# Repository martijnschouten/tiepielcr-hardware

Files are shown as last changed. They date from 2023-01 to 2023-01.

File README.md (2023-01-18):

# TiePieLCR hardware
Contains the design files of the TiePieLCR multi-frequency spectrometer front-end. The TiePieLCR consists of a TiePie engineering HS5 with custom PCB and a 3D printed case. The front-end contains an instrumentation amplifier to measure differential voltages, a transimpedance amplifier to measure currents and  voltage controlled current source to be able to do safe current controlled measurements on humans.

To make one of your own you can use the supplied gerber files to get a PCB fabricated. To make some improments to design you can open the schematic in Kicad. The STL's and Inventor files of the case for the electronics can also be found in this repository.



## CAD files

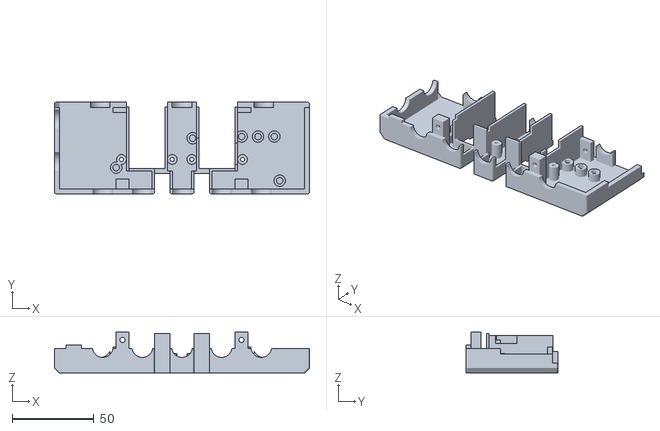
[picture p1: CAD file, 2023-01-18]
casing/Part1.stl
156.0 x 56.0 x 25.0

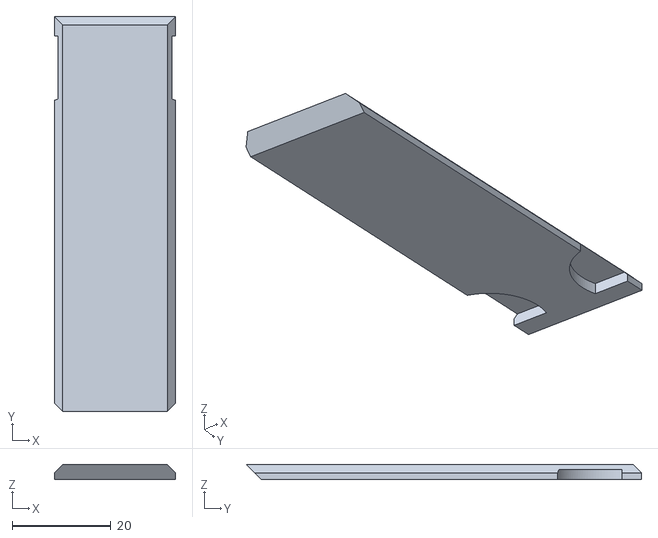
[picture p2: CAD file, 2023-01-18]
casing/Part3.stl
24.6 x 80.1 x 3.00

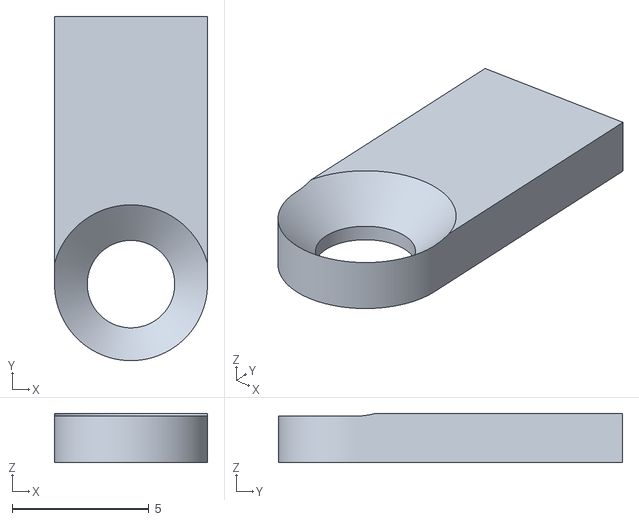
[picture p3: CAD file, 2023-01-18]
casing/Part4.stl
5.60 x 12.6 x 1.80

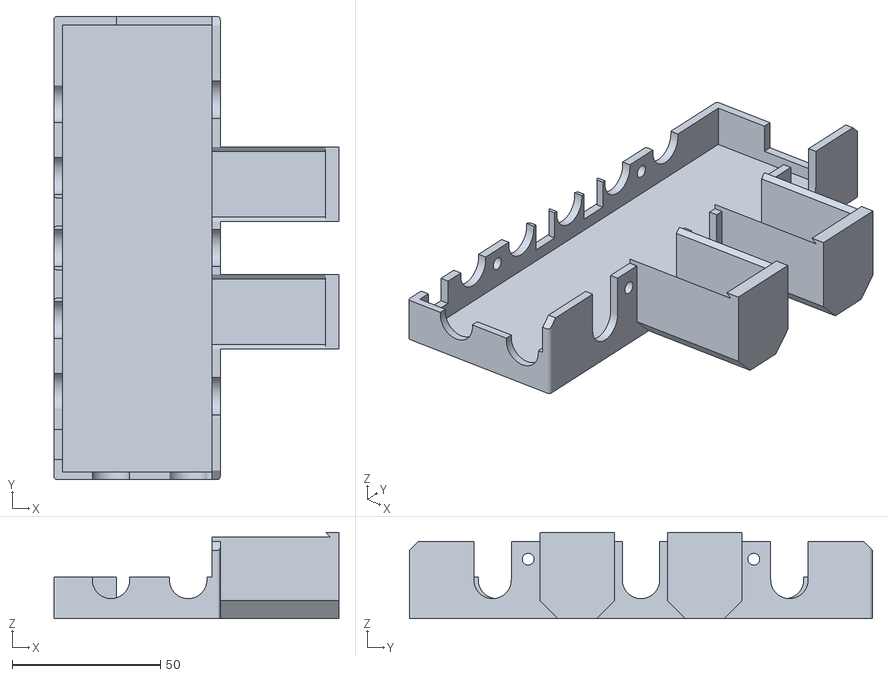
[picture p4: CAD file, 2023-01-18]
casing/Part2.stl
96.0 x 156.0 x 29.0

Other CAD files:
casing/Assembly1.iam
casing/Part1.ipt
casing/Part2.ipt
casing/Part3.ipt
casing/Part4.ipt

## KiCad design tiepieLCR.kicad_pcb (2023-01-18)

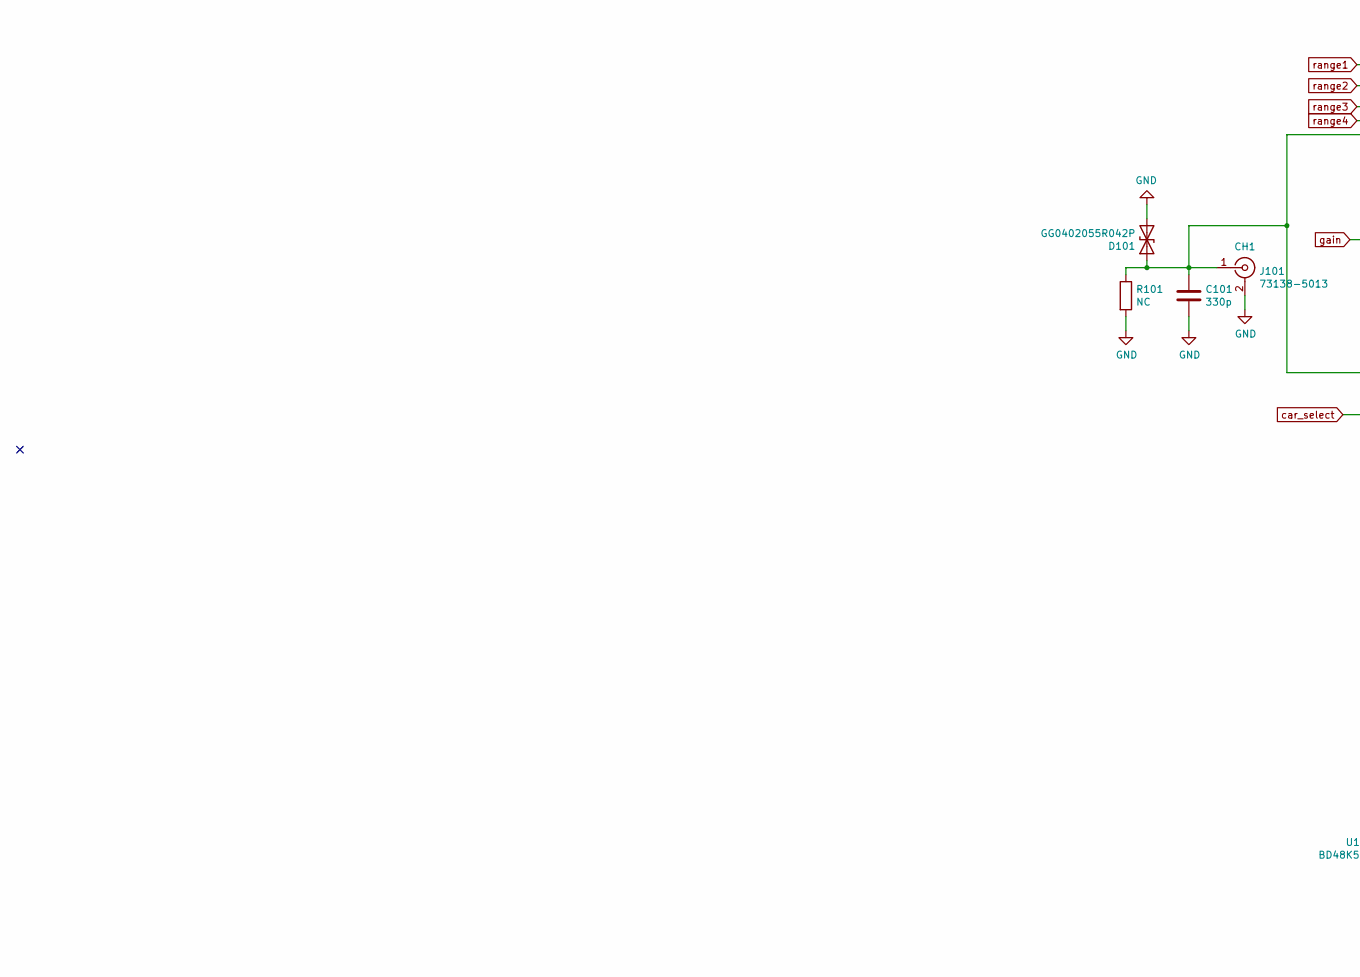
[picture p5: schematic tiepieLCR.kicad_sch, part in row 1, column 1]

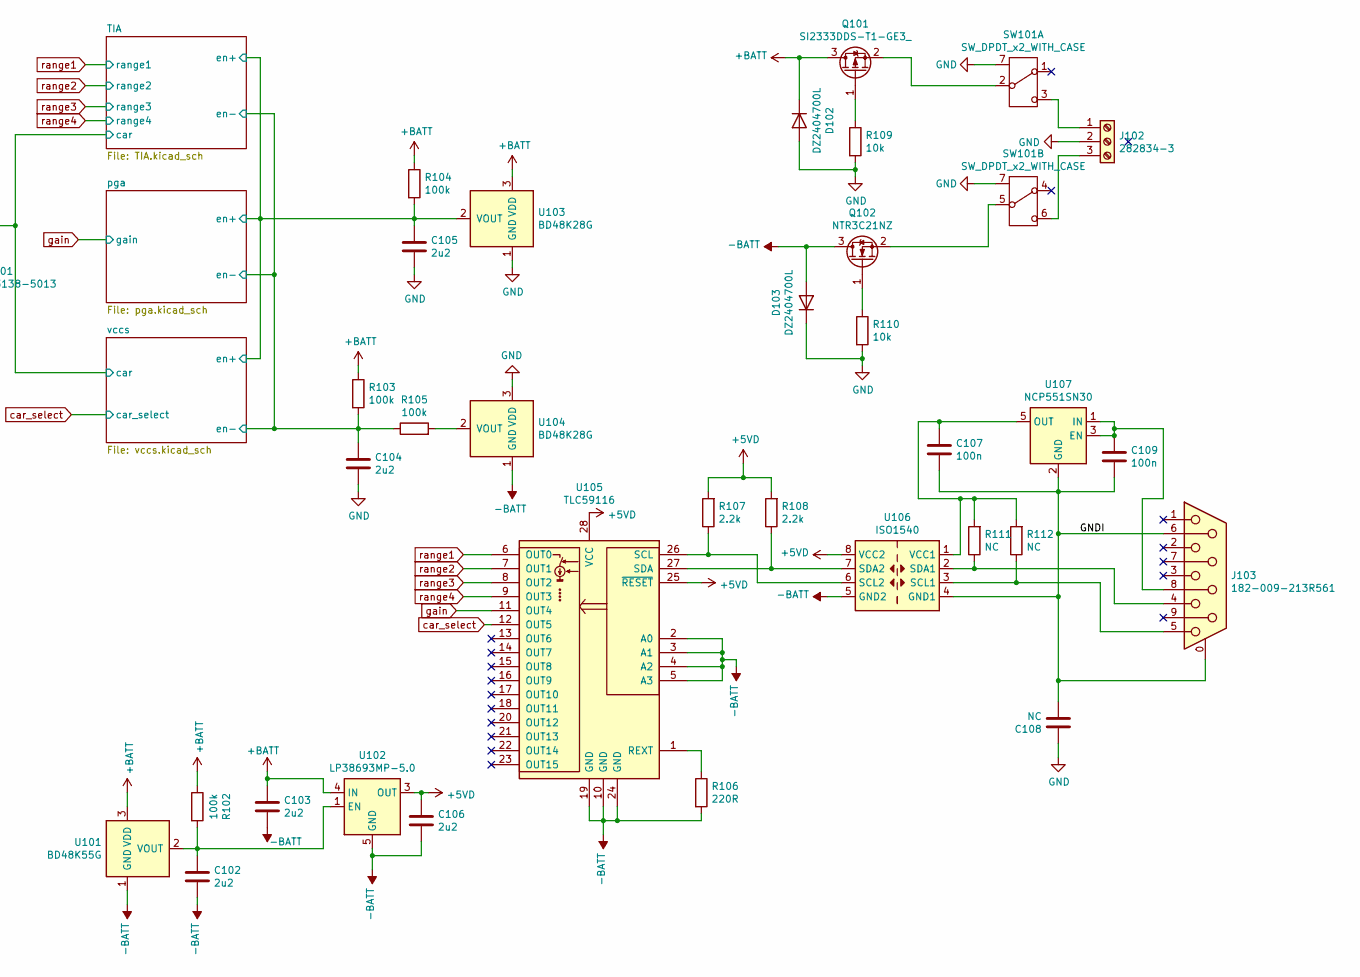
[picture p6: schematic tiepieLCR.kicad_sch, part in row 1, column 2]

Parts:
C101: 330p; C_0603_1608Metric_Pad1.05x0.95mm_HandSolder
C102, C103, C104, C105, C106: 2u2; C_0603_1608Metric_Pad1.05x0.95mm_HandSolder
C107, C109: 100n; C_0603_1608Metric_Pad1.05x0.95mm_HandSolder
C108: NC; C_1206_3216Metric
D101: GG0402055R042P; D_0402_1005Metric
D102, D103: DZ2404700L; D_SOD-128
J101: 73138-5013; 0731385033
J102: 282834-3; TerminalBlock_TE_282834-3_1x03_P2.54mm_Horizontal
J103: 182-009-213R561; DSUB-9_Female_Horizontal_P2.77x2.84mm_EdgePinOffset7.70mm_H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
Q101: SI2333DDS-T1-GE3_; SOT-23
Q102: NTR3C21NZ; SOT-23
R101, R111, R112: NC; R_0603_1608Metric_Pad1.05x0.95mm_HandSolder
R102, R103, R104, R105: 100k; R_0603_1608Metric_Pad1.05x0.95mm_HandSolder
R106: 220R; R_0603_1608Metric_Pad1.05x0.95mm_HandSolder
R107, R108: 2.2k; R_0603_1608Metric_Pad1.05x0.95mm_HandSolder
R109, R110: 10k; R_0603_1608Metric_Pad1.05x0.95mm_HandSolder
SW101: SW_DPDT_x2_WITH_CASE; EG2219
U101: BD48K55G; SOT-23
U102: LP38693MP-5.0; SOT-223-5
U103, U104: BD48K28G; SOT-23
U105: TLC59116; TSSOP-28_4.4x9.7mm_P0.65mm
U106: ISO1540; SOIC-8_3.9x4.9mm_P1.27mm
U107: NCP551SN30; SOT-23-5

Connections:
+5VD: C106.1, R107.2, R108.2, U102.3 (OUT), U105.25 (~RESET), U105.28 (VCC), U106.8 (VCC2); also elsewhere on the board
+BATT: C103.1, D102.1 (K), Q101.3 (D), R102.1, R103.1, R104.1, U101.3 (VDD), U102.4 (IN), U103.3 (VDD); also elsewhere on the board
-BATT: C102.2, C103.2, C106.2, D103.2 (A), Q102.3 (D), R106.2, U101.1 (GND), U102.5 (GND), U104.1 (GND), U105.2 (A0), U105.3 (A1), U105.4 (A2), U105.5 (A3), U105.10 (GND), U105.19 (GND), U105.24 (GND), U106.5 (GND2); also elsewhere on the board
/GNDI: C107.2, C108.2, C109.2, J103.0 (PAD), J103.6 (GND), U106.4 (GND1), U107.2 (GND)
/TIA/car: C101.1, D101.1 (A1), J101.1 (In), R101.1; also elsewhere on the board
/TIA/en+: C105.1, R104.2, U103.2 (VOUT); also elsewhere on the board
/TIA/en-: C104.1, R103.2, R105.1; also elsewhere on the board
GND: C101.2, C104.2, C105.2, C108.1, D101.2 (A2), D102.2 (A), D103.1 (K), J101.2 (Ext), J102.2, R101.2, R109.2, R110.2, SW101.7 (CASE), U103.1 (GND), U104.3 (VDD); also elsewhere on the board
unnamed: C102.1, R102.2, U101.2 (VOUT), U102.1 (EN)
unnamed: C107.1, R111.2, R112.2, U106.1 (VCC1), U107.5 (OUT)
unnamed: C109.1, J103.8 (OUT), U107.1 (IN), U107.3 (EN)
unnamed: J102.1, SW101.3 (C)
unnamed: J102.3, SW101.6 (C)
unnamed: J103.4 (SDA), R111.1, U106.2 (SDA1)
unnamed: J103.5 (SCL), R112.1, U106.3 (SCL1)
unnamed: Q101.1 (G), R109.1
unnamed: Q101.2 (S), SW101.2 (B)
unnamed: Q102.1 (G), R110.1
unnamed: Q102.2 (S), SW101.5 (B)
unnamed: R105.2, U104.2 (VOUT)
unnamed: R106.1, U105.1 (REXT)
unnamed: R107.1, U105.26 (SCL), U106.6 (SCL2)
unnamed: R108.1, U105.27 (SDA), U106.7 (SDA2)
car_select: U105.12 (OUT5); also elsewhere on the board
gain: U105.11 (OUT4); also elsewhere on the board
range1: U105.6 (OUT0); also elsewhere on the board
range2: U105.7 (OUT1); also elsewhere on the board
range3: U105.8 (OUT2); also elsewhere on the board
range4: U105.9 (OUT3); also elsewhere on the board

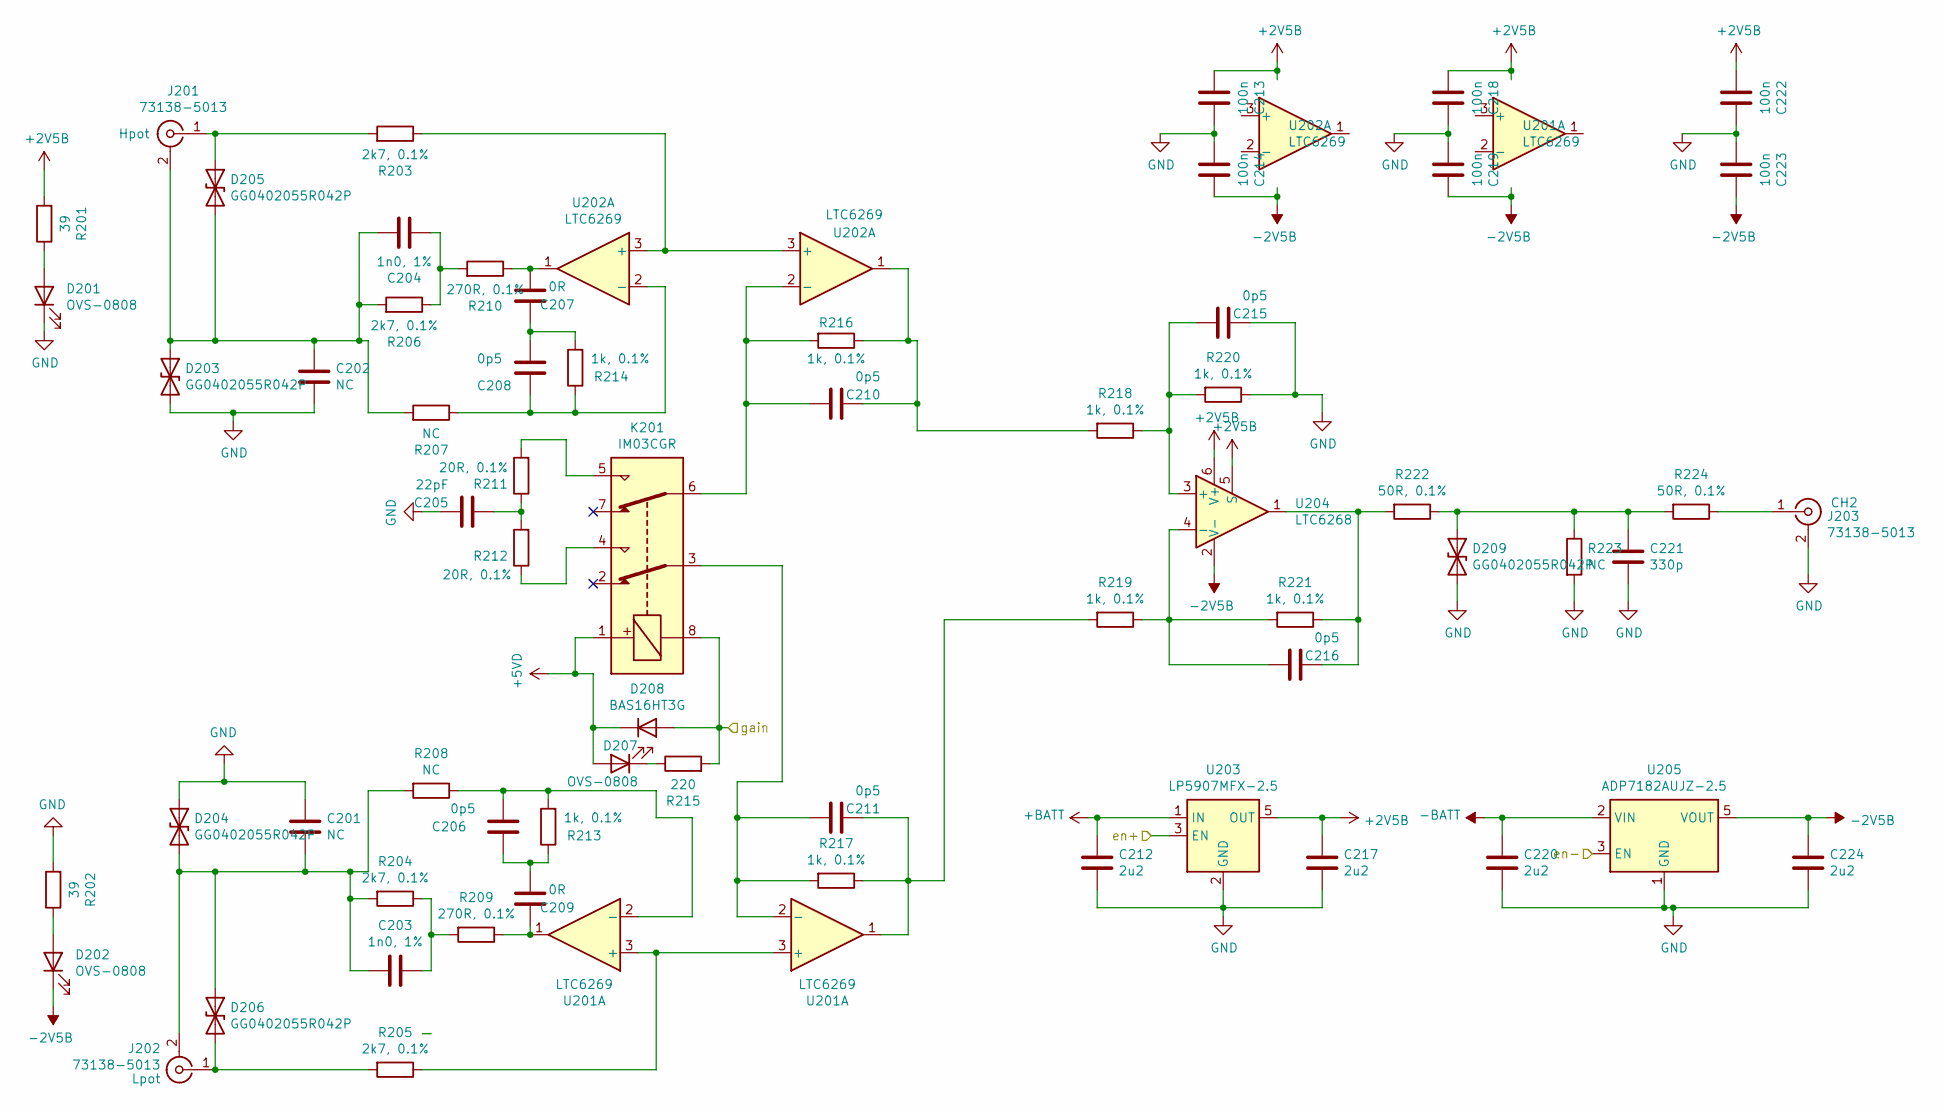
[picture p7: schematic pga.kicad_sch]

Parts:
C201, C202: NC; C_0603_1608Metric_Pad1.05x0.95mm_HandSolder
C203, C204: 1n0, 1%; C_0603_1608Metric_Pad1.05x0.95mm_HandSolder
C205: 22pF; C_0603_1608Metric_Pad1.05x0.95mm_HandSolder
C206, C208, C210, C211, C215, C216: 0p5; C_0603_1608Metric_Pad1.05x0.95mm_HandSolder
C207, C209: 0R; C_0603_1608Metric_Pad1.05x0.95mm_HandSolder
C212, C217, C220, C224: 2u2; C_0603_1608Metric_Pad1.05x0.95mm_HandSolder
C213, C214, C218, C219, C222, C223: 100n; C_0603_1608Metric_Pad1.05x0.95mm_HandSolder
C221: 330p; C_0603_1608Metric_Pad1.05x0.95mm_HandSolder
D201, D202, D207: OVS-0808; LED_0805_2012Metric
D203, D204, D205, D206, D209: GG0402055R042P; D_0402_1005Metric
D208: BAS16HT3G; D_SOD-323
J201, J202, J203: 73138-5013; 0731385033
K201: IM03CGR; 1462039-4
R201, R202: 39; R_0603_1608Metric_Pad1.05x0.95mm_HandSolder
R203, R204, R205, R206: 2k7, 0.1%; R_0603_1608Metric_Pad1.05x0.95mm_HandSolder
R207, R208, R223: NC; R_0603_1608Metric_Pad1.05x0.95mm_HandSolder
R209, R210: 270R, 0.1%; R_0603_1608Metric_Pad1.05x0.95mm_HandSolder
R211, R212: 20R, 0.1%; R_0603_1608Metric_Pad1.05x0.95mm_HandSolder
R213, R214, R216, R217, R218, R219, R220, R221: 1k, 0.1%; R_0603_1608Metric
R215: 220; R_0603_1608Metric_Pad1.05x0.95mm_HandSolder
R222, R224: 50R, 0.1%; R_0603_1608Metric
U201, U202: LTC6269; MSOP-8_3x3mm_P0.65mm
U203: LP5907MFX-2.5; SOT-23-5
U204: LTC6268; SOT-23-6_Handsoldering
U205: ADP7182AUJZ-2.5; TSOT-23-5

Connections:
+2V5B: C213.2, C217.2, C218.2, C222.2, R201.2, U201.8 (V+), U202.8 (V+), U203.5 (OUT), U204.5 (S), U204.6 (V+)
+5VD: D207.2 (A), D208.1 (K), K201.1; also elsewhere on the board
+BATT: C212.2, U203.1 (IN); also elsewhere on the board
-2V5B: C214.1, C219.1, C223.1, C224.2, D202.1 (K), U201.4 (V-), U202.4 (V-), U204.2 (V-), U205.5 (VOUT)
-BATT: C220.2, U205.2 (VIN); also elsewhere on the board
/TIA/en+: U203.3 (EN); also elsewhere on the board
/TIA/en-: U205.3 (EN); also elsewhere on the board
GND: C201.1, C202.2, C205.2, C212.1, C213.1, C214.2, C215.1, C217.1, C218.1, C219.2, C220.1, C221.2, C222.1, C223.2, C224.1, D201.1 (K), D203.2 (A2), D204.1 (A1), D209.2 (A2), J203.2 (Ext), R202.2, R220.1, R223.2, U203.2 (GND), U205.1 (GND); also elsewhere on the board
unnamed: C201.2, C203.2, D204.2 (A2), D206.1 (A1), J202.2 (Ext), R204.2, R208.2
unnamed: C202.1, C204.2, D203.1 (A1), D205.2 (A2), J201.2 (Ext), R206.2, R207.2
unnamed: C203.1, R204.1, R209.2
unnamed: C204.1, R206.1, R210.2
unnamed: C205.1, R211.1, R212.2
unnamed: C206.2, C209.2, R213.1
unnamed: C207.1, C208.1, R214.2
unnamed: C215.2, R218.1, R220.2, U204.3 (+)
unnamed: C216.1, R221.1, R222.2, U204.1
unnamed: C216.2, R219.1, R221.2, U204.4 (-)
unnamed: C221.1, D209.1 (A1), R222.1, R223.1, R224.2
unnamed: D201.2 (A), R201.1
unnamed: D202.2 (A), R202.1
unnamed: D205.1 (A1), J201.1 (In), R203.2
unnamed: D206.2 (A2), J202.1 (In), R205.2
unnamed: D207.1 (K), R215.1
unnamed: J203.1 (In), R224.1
unnamed: K201.4, R212.1
unnamed: K201.5, R211.2
unnamed: R203.1, U202.3 (+), U202.5 (+)
unnamed: R205.1, U201.3 (+), U201.5 (+)
gain: D208.2 (A), K201.8, R215.2; also elsewhere on the board

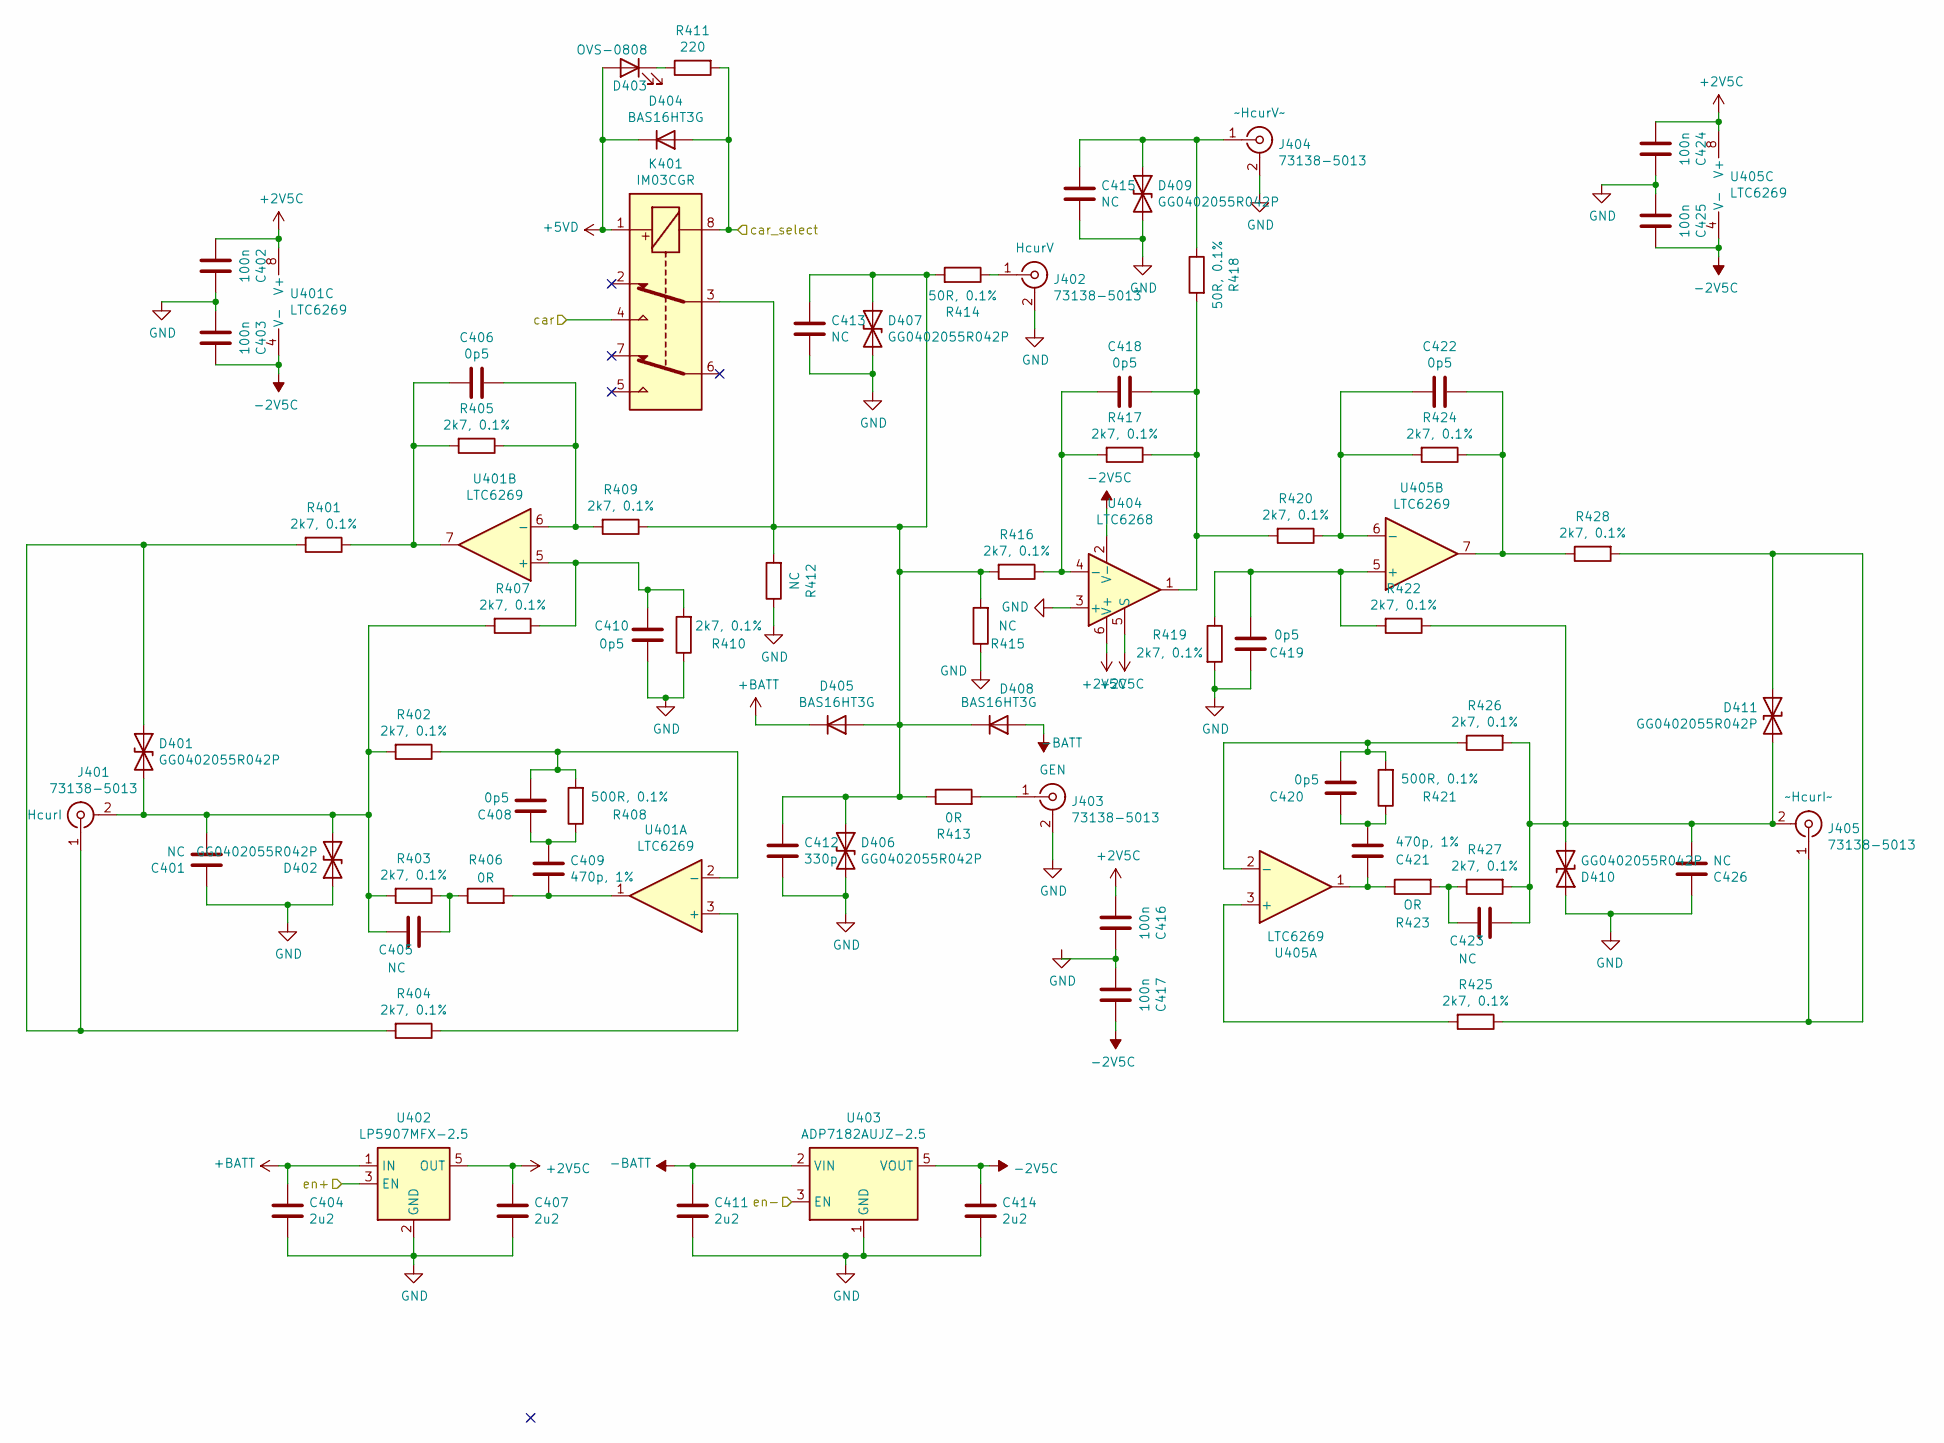
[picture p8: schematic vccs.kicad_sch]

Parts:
C401, C405, C413, C415, C423, C426: NC; C_0603_1608Metric_Pad1.05x0.95mm_HandSolder
C402, C403, C416, C417, C424, C425: 100n; C_0603_1608Metric_Pad1.05x0.95mm_HandSolder
C404, C407, C411, C414: 2u2; C_0603_1608Metric_Pad1.05x0.95mm_HandSolder
C406, C408, C410, C418, C419, C420, C422: 0p5; C_0603_1608Metric_Pad1.05x0.95mm_HandSolder
C409, C421: 470p, 1%; C_0603_1608Metric_Pad1.05x0.95mm_HandSolder
C412: 330p; C_0603_1608Metric_Pad1.05x0.95mm_HandSolder
D401, D402, D406, D407, D409, D410, D411: GG0402055R042P; D_0402_1005Metric
D403: OVS-0808; LED_0805_2012Metric
D404, D405, D408: BAS16HT3G; D_SOD-323
J401, J402, J403, J404, J405: 73138-5013; 0731385033
K401: IM03CGR; 1462039-4
R401, R402, R403, R404, R405, R407, R409, R410, R416, R417, R419, R420, R422, R424, R425, R426, R427, R428: 2k7, 0.1%; R_0603_1608Metric_Pad1.05x0.95mm_HandSolder
R406, R413: 0R; R_0603_1608Metric_Pad1.05x0.95mm_HandSolder
R408, R421: 500R, 0.1%; R_0603_1608Metric_Pad1.05x0.95mm_HandSolder
R411: 220; R_0603_1608Metric_Pad1.05x0.95mm_HandSolder
R412, R415: NC; R_0603_1608Metric_Pad1.05x0.95mm_HandSolder
R414, R418: 50R, 0.1%; R_0603_1608Metric
R423: OR; R_0603_1608Metric_Pad1.05x0.95mm_HandSolder
U401, U405: LTC6269; MSOP-8_3x3mm_P0.65mm
U402: LP5907MFX-2.5; SOT-23-5
U403: ADP7182AUJZ-2.5; TSOT-23-5
U404: LTC6268; SOT-23-6_Handsoldering

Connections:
+2V5C: C402.2, C407.2, C416.2, C424.2, U401.8 (V+), U402.5 (OUT), U404.5 (S), U404.6 (V+), U405.8 (V+)
+5VD: D403.2 (A), D404.1 (K), K401.1; also elsewhere on the board
+BATT: C404.2, D405.1 (K), U402.1 (IN); also elsewhere on the board
-2V5C: C403.1, C414.2, C417.1, C425.1, U401.4 (V-), U403.5 (VOUT), U404.2 (V-), U405.4 (V-)
-BATT: C411.2, D408.2 (A), U403.2 (VIN); also elsewhere on the board
/TIA/car: K401.4; also elsewhere on the board
/TIA/en+: U402.3 (EN); also elsewhere on the board
/TIA/en-: U403.3 (EN); also elsewhere on the board
GND: C401.1, C402.1, C403.2, C404.1, C407.1, C410.2, C411.1, C412.1, C413.1, C414.1, C415.1, C419.2, C424.1, C425.2, C426.1, D402.1 (A1), D406.2 (A2), D407.2 (A2), D409.2 (A2), D410.1 (A1), J402.2 (Ext), J403.2 (Ext), J404.2 (Ext), R410.1, R412.1, R415.1, R419.2, U402.2 (GND), U403.1 (GND), U404.3 (+); also elsewhere on the board
unnamed: C401.2, C405.1, D401.2 (A2), D402.2 (A2), J401.2 (Ext), R402.2, R403.2, R407.2
unnamed: C405.2, R403.1, R406.1
unnamed: C406.1, R405.1, R409.2, U401.6 (-)
unnamed: C406.2, R401.1, R405.2, U401.7
unnamed: C408.1, R402.1, R408.2, U401.2 (-)
unnamed: C408.2, C409.2, R408.1
unnamed: C409.1, R406.2, U401.1
unnamed: C410.1, R407.1, R410.2, U401.5 (+)
unnamed: C412.2, C413.2, D405.2 (A), D406.1 (A1), D407.1 (A1), D408.1 (K), K401.3, R409.1, R412.2, R413.1, R414.2, R415.2, R416.2
unnamed: C415.2, D409.1 (A1), J404.1 (In), R418.1
unnamed: C416.1, C417.2
unnamed: C418.1, R417.1, R418.2, R420.2, U404.1
unnamed: C418.2, R416.1, R417.2, U404.4 (-)
unnamed: C419.1, R419.1, R422.2, U405.5 (+)
unnamed: C420.1, R421.2, R426.1, U405.2 (-)
unnamed: C420.2, C421.2, R421.1
unnamed: C421.1, R423.1, U405.1
unnamed: C422.1, R420.1, R424.2, U405.6 (-)
unnamed: C422.2, R424.1, R428.1, U405.7
unnamed: C423.1, R423.2, R427.1
unnamed: C423.2, C426.2, D410.2 (A2), D411.2 (A2), J405.2 (Ext), R422.1, R426.2, R427.2
unnamed: D401.1 (A1), J401.1 (In), R401.2, R404.2
unnamed: D403.1 (K), R411.1
unnamed: D411.1 (A1), J405.1 (In), R425.1, R428.2
unnamed: J402.1 (In), R414.1
unnamed: J403.1 (In), R413.2
unnamed: R404.1, U401.3 (+)
unnamed: R425.2, U405.3 (+)
car_select: D404.2 (A), K401.8, R411.2; also elsewhere on the board

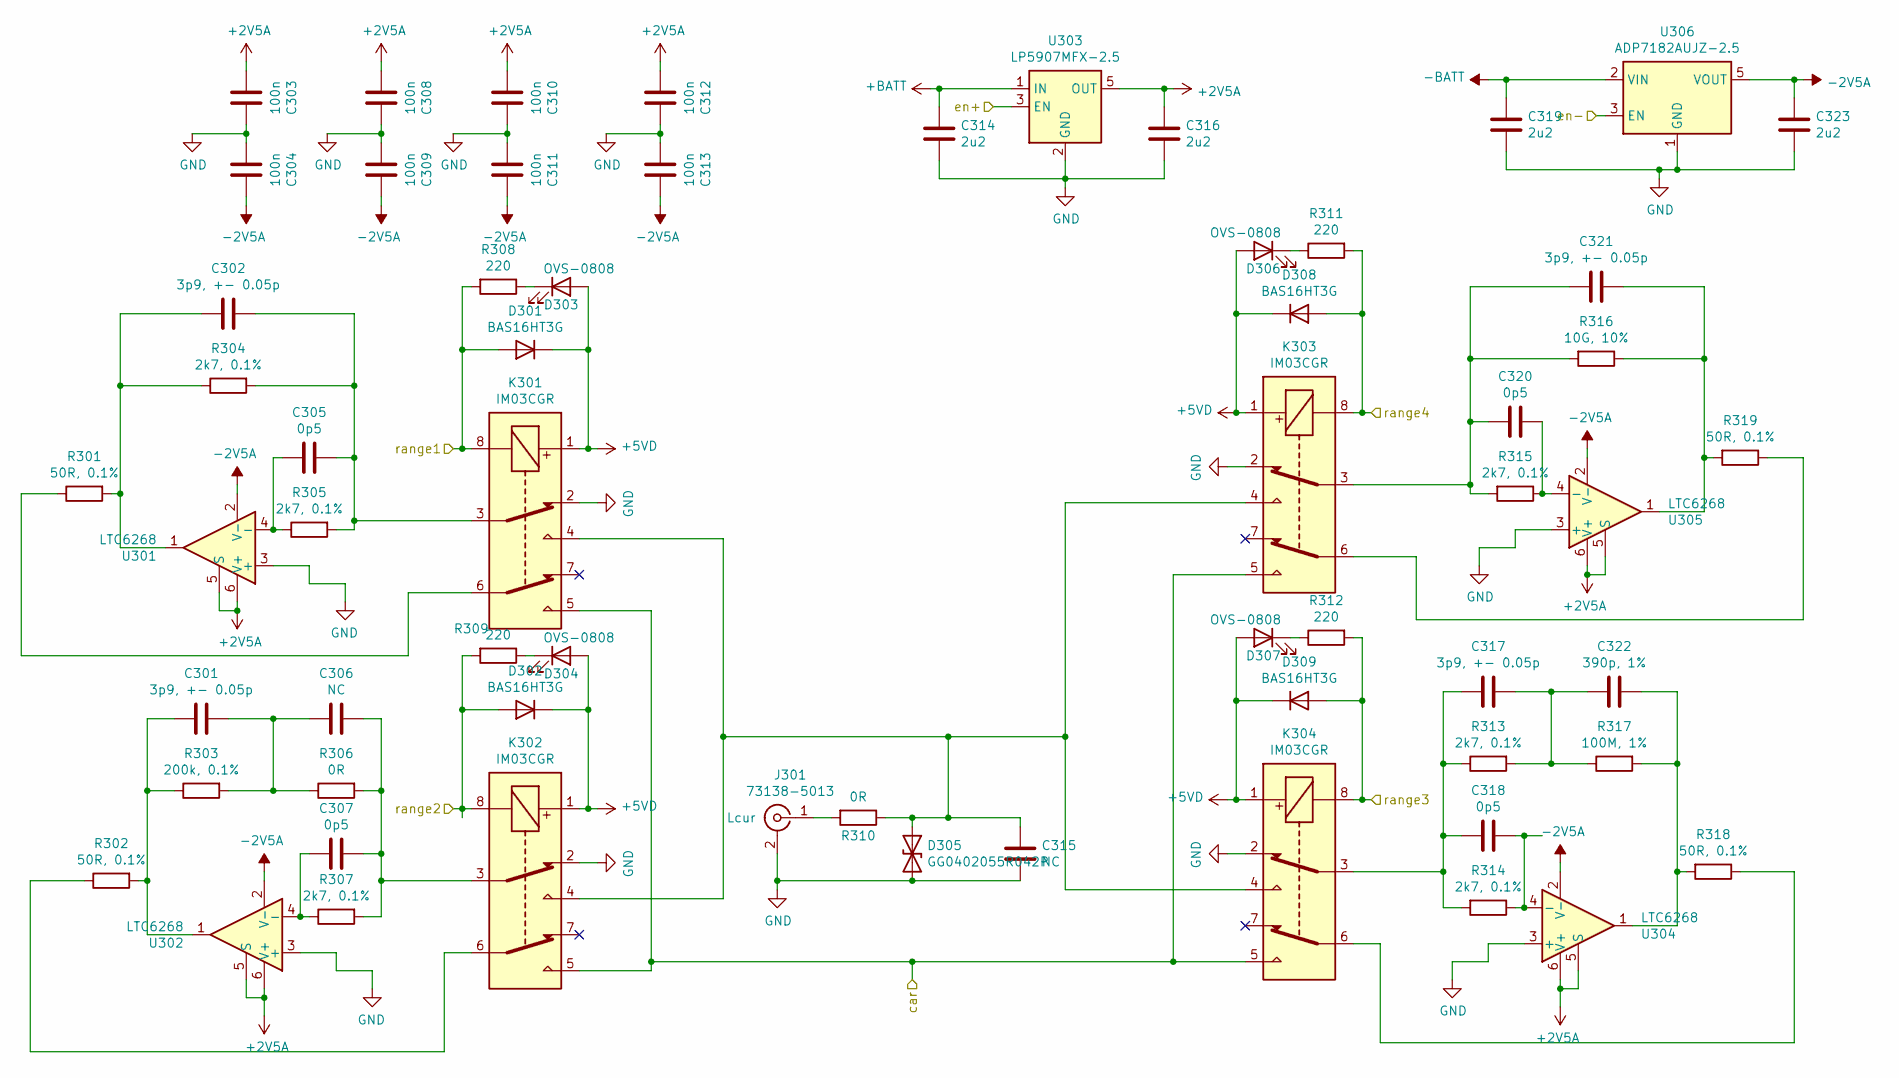
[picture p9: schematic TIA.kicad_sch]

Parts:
C301, C302, C317, C321: 3p9, +- 0.05p; C_0603_1608Metric_Pad1.05x0.95mm_HandSolder
C303, C304, C308, C309, C310, C311, C312, C313: 100n; C_0603_1608Metric_Pad1.05x0.95mm_HandSolder
C305, C307, C318, C320: 0p5; C_0603_1608Metric_Pad1.05x0.95mm_HandSolder
C306, C315: NC; C_0603_1608Metric_Pad1.05x0.95mm_HandSolder
C314, C316, C319, C323: 2u2; C_0603_1608Metric_Pad1.05x0.95mm_HandSolder
C322: 390p, 1%; C_0603_1608Metric_Pad1.05x0.95mm_HandSolder
D301, D302, D308, D309: BAS16HT3G; D_SOD-323
D303, D304, D306, D307: OVS-0808; LED_0805_2012Metric
D305: GG0402055R042P; D_0402_1005Metric
J301: 73138-5013; 0731385033
K301, K302, K303, K304: IM03CGR; 1462039-4
R301, R302, R318, R319: 50R, 0.1%; R_0603_1608Metric
R303: 200k, 0.1%; R_1206_3216Metric_Pad1.42x1.75mm_HandSolder
R304, R305, R307, R313, R314, R315: 2k7, 0.1%; R_0603_1608Metric_Pad1.05x0.95mm_HandSolder
R306, R310: 0R; R_0603_1608Metric_Pad1.05x0.95mm_HandSolder
R308, R309, R311, R312: 220; R_0603_1608Metric_Pad1.05x0.95mm_HandSolder
R316: 10G, 10%; R_1206_3216Metric_Pad1.42x1.75mm_HandSolder
R317: 100M, 1%; R_1206_3216Metric_Pad1.42x1.75mm_HandSolder
U301, U302, U304, U305: LTC6268; SOT-23-6_Handsoldering
U303: LP5907MFX-2.5; SOT-23-5
U306: ADP7182AUJZ-2.5; TSOT-23-5

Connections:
+2V5A: C303.2, C308.2, C310.2, C312.2, C316.2, U301.5 (S), U301.6 (V+), U302.5 (S), U302.6 (V+), U303.5 (OUT), U304.5 (S), U304.6 (V+), U305.5 (S), U305.6 (V+)
+5VD: D301.1 (K), D302.1 (K), D303.2 (A), D304.2 (A), D306.2 (A), D307.2 (A), D308.1 (K), D309.1 (K), K301.1, K302.1, K303.1, K304.1; also elsewhere on the board
+BATT: C314.2, U303.1 (IN); also elsewhere on the board
-2V5A: C304.1, C309.1, C311.1, C313.1, C323.2, U301.2 (V-), U302.2 (V-), U304.2 (V-), U305.2 (V-), U306.5 (VOUT)
-BATT: C319.2, U306.2 (VIN); also elsewhere on the board
/TIA/car: K301.5, K302.5, K303.5, K304.5; also elsewhere on the board
/TIA/en+: U303.3 (EN); also elsewhere on the board
/TIA/en-: U306.3 (EN); also elsewhere on the board
GND: C303.1, C304.2, C308.1, C309.2, C310.1, C311.2, C312.1, C313.2, C314.1, C315.2, C316.1, C319.1, C323.1, D305.2 (A2), J301.2 (Ext), K301.2, K302.2, K303.2, K304.2, U301.3 (+), U302.3 (+), U303.2 (GND), U304.3 (+), U305.3 (+), U306.1 (GND); also elsewhere on the board
unnamed: C301.1, R302.2, R303.1, U302.1
unnamed: C301.2, C306.1, R303.2, R306.1
unnamed: C302.1, R301.2, R304.1, U301.1
unnamed: C302.2, C305.2, K301.3, R304.2, R305.2
unnamed: C305.1, R305.1, U301.4 (-)
unnamed: C306.2, C307.2, K302.3, R306.2, R307.2
unnamed: C307.1, R307.1, U302.4 (-)
unnamed: C315.1, D305.1 (A1), K301.4, K302.4, K303.4, K304.4, R310.1
unnamed: C317.1, C318.1, K304.3, R313.1, R314.2
unnamed: C317.2, C322.1, R313.2, R317.1
unnamed: C318.2, R314.1, U304.4 (-)
unnamed: C320.1, C321.2, K303.3, R315.2, R316.2
unnamed: C320.2, R315.1, U305.4 (-)
unnamed: C321.1, R316.1, R319.2, U305.1
unnamed: C322.2, R317.2, R318.2, U304.1
unnamed: D303.1 (K), R308.1
unnamed: D304.1 (K), R309.1
unnamed: D306.1 (K), R311.1
unnamed: D307.1 (K), R312.1
unnamed: J301.1 (In), R310.2
unnamed: K301.6, R301.1
unnamed: K302.6, R302.1
unnamed: K303.6, R319.1
unnamed: K304.6, R318.1
range1: D301.2 (A), K301.8, R308.2; also elsewhere on the board
range2: D302.2 (A), K302.8, R309.2; also elsewhere on the board
range3: D309.2 (A), K304.8, R312.2; also elsewhere on the board
range4: D308.2 (A), K303.8, R311.2; also elsewhere on the board

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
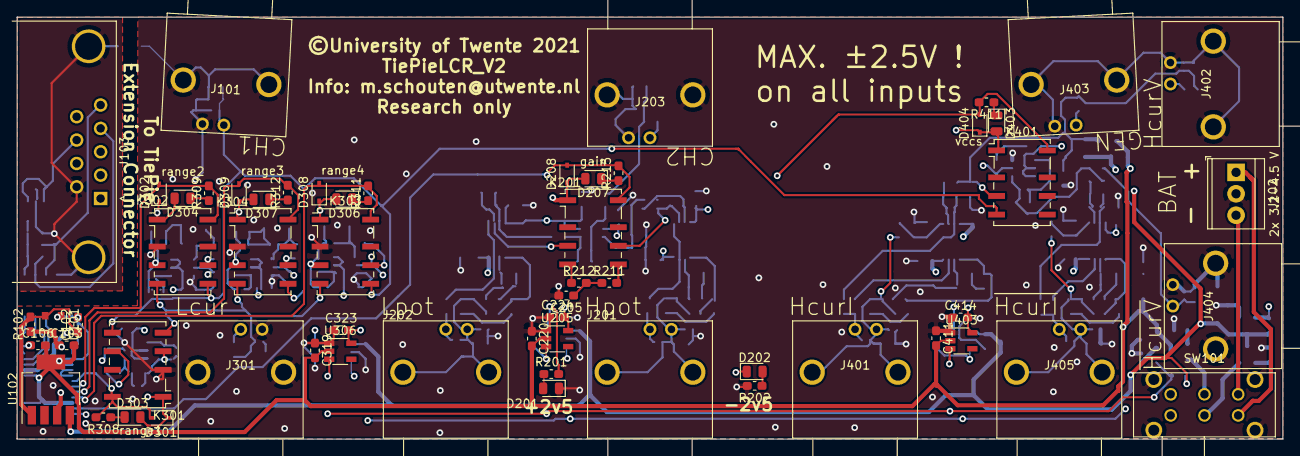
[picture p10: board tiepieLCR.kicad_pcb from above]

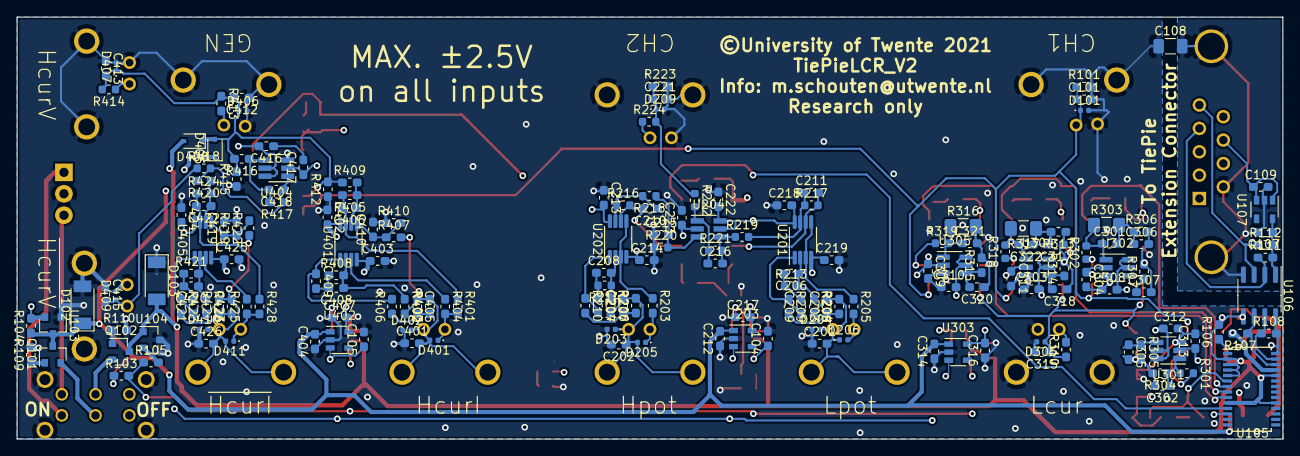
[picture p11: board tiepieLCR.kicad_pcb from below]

Board: 4 copper layers, 150.0 x 50.0 mm, 241 parts (182 on the bottom side), 116 nets.

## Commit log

2023-01-18 added cad files
    [TIA.kicad_sch, TIA.sch, cal.sch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]
2023-01-18 added casing
    [Assembly1.iam, Part1.ipt, Part1.stl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]

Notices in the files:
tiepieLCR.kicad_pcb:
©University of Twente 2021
